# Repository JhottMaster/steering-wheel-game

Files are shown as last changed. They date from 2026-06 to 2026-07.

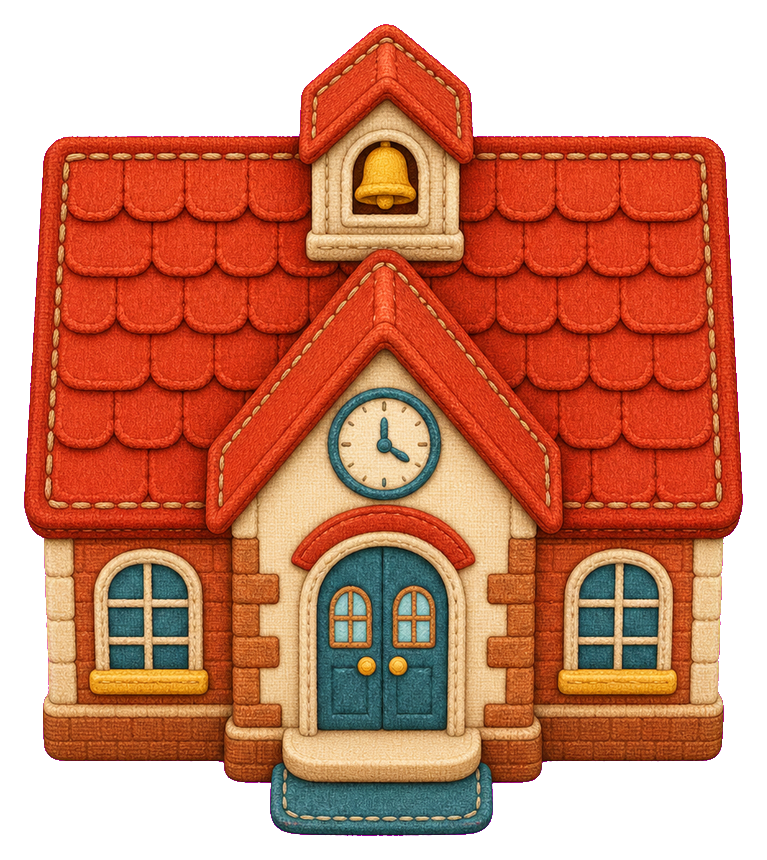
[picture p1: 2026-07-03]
controller_game/assets/sprites/building_school_ai_01.png

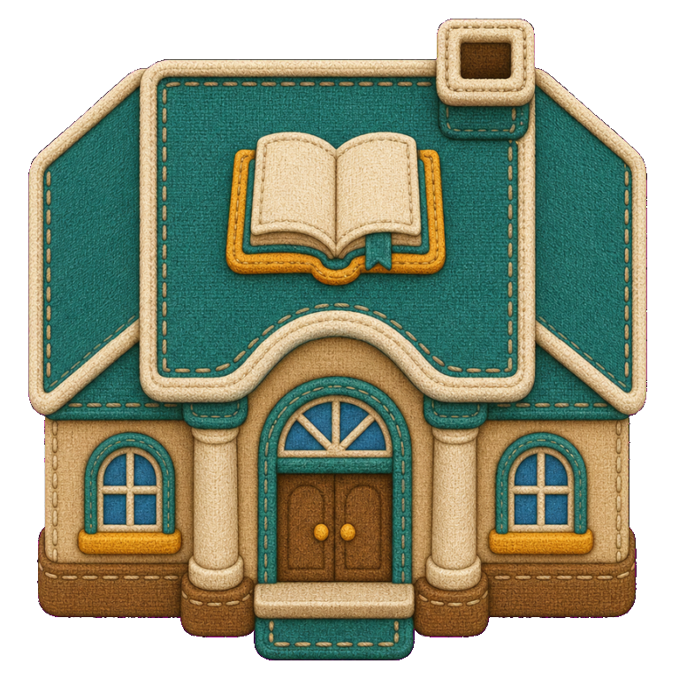
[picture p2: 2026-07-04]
controller_game/assets/sprites/building_library.png

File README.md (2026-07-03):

# Toddler Steering Wheel

This repo contains the CAD work, firmware, and game experiments for the toddler steering wheel project.

## Main Parts

- [`controller_game`](controller_game): the shared `raylib` game code for both Windows desktop development and Raspberry Pi console deployment
- [`firmware`](firmware): microcontroller sketches for streaming steering data
- [`docs`](docs): project notes and setup docs
- [`toddler_steering_wheel.py`](toddler_steering_wheel.py): CADQuery model for printed parts

## Shared Game Workflow

The game now lives in [`controller_game`](controller_game) and is configured for:

- Raspberry Pi OS `Lite`
- `raylib` built with `PLATFORM_DRM`
- fixed `1920x1080` output
- `UDP` controller input on port `4210`
- the existing Windows `MSYS2` desktop build loop

Quick path on the Pi:

```bash
sudo apt update
sudo apt install -y git build-essential \
  libdrm-dev libegl1-mesa-dev libgles2-mesa-dev libgbm-dev libasound2-dev

git clone --depth 1 https://github.com/raysan5/raylib.git
cd raylib/src
make PLATFORM=PLATFORM_DRM

cd /path/to/steering-wheel-game/controller_game
make -f Makefile.raspberry_pi
./build/bin/steering_wheel_console
```

For Windows desktop work, run:

```text
controller_game\windows_build.bat
controller_game\windows_test.bat
```

For Windows-to-Pi remote deploys, use:

```text
controller_game\deploy_to_raspberry_pi.bat
controller_game\stop_raspberry_pi_game.bat
```

Create `controller_game\raspberry_pi_config.bat` from `controller_game\raspberry_pi_config.example.bat` before deploying. The deploy script copies the game package to the Pi, builds it remotely, stops any running copy, starts the new build detached, and writes runtime logs to `/tmp/steering_wheel_console.log`.

More detail is in [`controller_game/README.md`](controller_game/README.md).

Game source layout and future-edit guidelines are in [`controller_game/DEVELOPMENT_GUIDELINES.md`](controller_game/DEVELOPMENT_GUIDELINES.md).

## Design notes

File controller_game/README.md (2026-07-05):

# Steering Wheel Controller Game

Shared `raylib` game code for both the Windows desktop dev loop and the Raspberry Pi console build.

`src/main.cpp` owns the app setup and frame loop so it remains a useful starting point. Most modules keep their implementation in the header to make browsing the game easier. The rest of `src/` is organized by responsibility:

- `src/game/`: Road Carpet Drive logic, assets, audio, and game rendering
- `src/app/`: shared app-level state such as app mode, logical controller buttons, and pause menu behavior
- `src/input/`: shared controller packet polling and packet-to-`SensorFrame` parsing behavior
- `src/views/`: secondary screens such as the hardware test dashboard
- `src/platform/`: Windows and Linux/Raspberry Pi networking, local IP lookup, and window defaults

This keeps networking, local IP discovery, window defaults, and small `raylib` API differences out of gameplay code.

Project structure preferences are captured in [`DEVELOPMENT_GUIDELINES.md`](DEVELOPMENT_GUIDELINES.md). In short: prefer header-oriented modules for this small game, keep `main.cpp` readable enough to understand the frame loop, and keep platform-specific socket/window details behind `src/platform/`.

## What It Does

- listens on `UDP` port `4210`
- expects packets like:

```text
qw=0.996,qx=0.012,qy=-0.084,qz=0.018,button1=0,button2=1
```

- the current controller firmware sends on input change and also forces a heartbeat packet at least every `200ms`
- on startup, the game immediately advertises itself over `UDP` broadcast on port `4211` so a controller can discover it
- once a controller is connected, the game stops broadcasting and only resumes if packets go stale for more than `5` seconds
- while rediscovering, the game sends a discovery beacon every `3` seconds and shows a disconnected banner in the game view

- defaults to the Road Carpet Drive game
- starts paused so a controller-only Raspberry Pi boot lands on a usable menu before gameplay begins
- press `T` to show the hardware test dashboard
- drives a toy car around a spreadsheet-authored toy-carpet city map
- uses generated sprites from `assets/sprites`
- draws roads, buildings, trees, bushes, coins, and spawn markers from `assets/cities/demo_city.csv`
- the current demo city has `32` collectible coins and `34` building props
- uses the CSV city data for spawn position, coin pickup, road/off-road behavior, and obstacle collision
- starts in button-throttle mode by default, with the car stopped until you accelerate
- gives button-throttle mode a higher top speed than auto-drive
- kicks up fading dust puffs and clamps speed harder when the car leaves the road
- adds animated kraken road encounters that wobble, growl when approached, and sink away when collected
- renders a steering wheel from quaternion-derived twist around the selected sensor axis
- displays the latest quaternion, derived Euler readout, and two button states from the controller
- shows `button2` as the red left lamp and `button1` as the green right lamp in test mode
- falls back to keyboard input if no recent packets arrive
- keeps the in-game HUD minimal: coins and speed stay visible, while diagnostics such as IP, FPS, and zoom live in the pause menu
- logs lightweight frame timing diagnostics to the terminal every `2` seconds while running
- desktop builds now default to a `1024x768` window to match the Raspberry Pi target layout more closely

## Controls

- `T`: toggle Road Carpet Drive / hardware test dashboard
- `A`: toggle auto-drive / button-throttle mode in the game
- in button-throttle mode, `button1` / up arrow accelerates
- in button-throttle mode, `button2` / down arrow brakes to a stop first and only engages reverse after the car has remained stopped for about `1` second
- `P`: use the sensor pitch-axis twist for steering
- `R`: use the sensor roll-axis twist for debug comparison
- `Y`: use the sensor yaw-axis twist for debug comparison
- `SPACE`: set the current sensor orientation as center
- controller recenter gesture: hold green (`button1`) and press red (`button2`) `3` times within `1.5` seconds
- controller pause gesture: hold green + red together for `3` seconds
- pause menu: steer left/right to choose, green selects, red resumes/goes back
- keyboard testing: up arrow also acts like green, down arrow also acts like red
- pause menu options: resume, restart, center wheel, quit, toggle acceleration mode, hardware test/back to game, zoom out, and zoom in
- left / right arrows: keyboard steering fallback input that automatically returns to center when released
- up arrow: desktop accelerate input in button-throttle mode
- down arrow: desktop brake/reverse input in button-throttle mode
- `-` / `=`: zoom the game camera out / in while tuning the city
- `0`: reset the game camera zoom
- `E`: toggle road art editor mode for tuning one hard-coded road piece and showing collision outlines
- in road art editor mode, `` ` `` / `~` toggles whether up/down selects the asset type or value field
- in road art editor field selection, up/down selects `scale_percent`, `footprint_percent`, `offset_x`, `offset_y`, `anchor_x`, or `anchor_y`
- in road art editor asset selection, up/down selects the road piece to tune
- in road art editor mode, left/right adjusts the selected value by `1` and auto-saves the config
- `F11`: toggle fullscreen on desktop builds
- `ESC`: quit

## Steering Notes

- gameplay steering uses quaternion-derived twist from the controller, not raw Euler steering angles
- the game tracks accumulated wheel rotation up to a `270` degree full-lock range instead of flipping direction after a half turn
- a small deadzone and blended response curve make it less twitchy near center while still giving stronger steering early in the turn
- reverse steering is automatically inverted so backing up behaves like a real car

## Assets

Generated game assets live in:

```text
assets/cities/
assets/sprites/
assets/sounds/
```

The current visual city is defined by:

```text
assets/cities/demo_city.csv
```

The carpet background is tiled from `terrain_carpet_tilemirror.png`; roads, props, buildings, coins, and the car are separate sprites drawn on top.

Fixed sprite filenames are used so the art can be replaced later without changing map files:

- `terrain_carpet_tilemirror.png`
- `road_horizontal_repeat.png`
- `road_vertical_repeat.png`
- `road_intersection_4way_crosswalks.png`
- `road_curve_bottom_right.png`
- `road_curve_bottom_left.png`
- `road_curve_top_right.png`
- `road_curve_top_left.png`
- `coin_star.png`
- `kraken_octopus_pop_sheet.png`
- `kraken_octopus_road_sheet.png`
- `toy_sports_car.png`
- `toy_car_tire.png`
- building sprites such as `building_house.png`, `building_shop.png`, and `building_fire_station.png`
- prop sprites such as `prop_bush_cluster.png`, `prop_evergreen.png`, and `prop_tree_round_ai_01.png`

Road curve filenames should match their semantic direction. For example, `road_curve_bottom_left.png`
is the art used by `CitySprite::kRoadCurveBottomLeft` and the `r_bl` city token.

Sound assets include:

- `carpet_cruise_loop.wav`
- `engine_large.ogg`, falling back to `toy_engine_loop.wav`
- `coin_chime.wav`
- `silent_beast_growl.mp3`: plays when an uncollected kraken first comes near the car
- `splash1.wav`: plays when a kraken is collected and sinks away
- optional fallback names `kraken_growl.wav` and `kraken_sink.wav` are also supported

To regenerate the current original art and sounds:

```text
python tools/generate_sounds.py
```

To regenerate simple procedural placeholder art that uses the same filenames loaded by the game:

```text
python tools/generate_assets.py
```

Some art helper scripts live in `tools/`, including tile mirroring and road alpha processing.

For quick city-layout tweaks without launching the game, there is also a lightweight visual CSV
editor:

```text
python tools/city_csv_editor.py
```

It shows the town as a clickable grid, includes row/column plus world-position data for each tile,
shows sprite previews behind the labels when available, and lets you edit/save the raw
pipe-separated cell contents directly.

## City CSV Format

The city map uses a spreadsheet-friendly CSV where each row is map `Y`, each column is map `X`, and each cell contains a pipe-separated list of things to draw in that tile.

Blank cells mean "just draw the tiled carpet background." A cell can contain one road tile plus any number of visual objects:

```csv
,,,,r_br,r_h|coin:star,r_h,r_bl
,house@256:280,,,r_v|coin:star
```

Cell contents use this shape:

```text
token
token@x:y
token@x:y*scale
token|token@x:y|token
```

Offsets are local tile pixels in a `512 x 512` authoring coordinate space, so `@256:256` means the center of a tile. The game currently renders each authored tile as `256 x 256` world pixels, which keeps the spreadsheet readable while making the city more compact. If an object has no offset, the parser places it at the tile center.

Current road tokens:

- `r_h`: horizontal road
- `r_v`: vertical road
- `r_x`: 4-way intersection
- `r_br`: curve connecting bottom and right
- `r_bl`: curve connecting bottom and left
- `r_tr`: curve connecting top and right
- `r_tl`: curve connecting top and left

Current object tokens:

- `coin:star`
- `kraken:pop`
- `kraken:road`
- `spawn:player`
- `tree:round`
- `tree:evergreen`
- `bush`
- `house`
- `shop`
- `school`
- `police`
- `fire_station`
- `library`

The parser for this format is in `src/game/city_map.h`. The same parsed city data drives rendering and gameplay:

- road tokens create drivable road shapes
- coin tokens create collectible coins
- kraken tokens create animated road encounters that pop/fade away when the car drives through them
- the HUD shows collected krakens separately from coins
- `spawn:player` sets the starting car position
- trees, bushes, and buildings create approximate obstacle collision shapes

Collision is intentionally based on authored geometry, not sprite alpha pixels. That keeps gameplay stable even as art is resized, feathered, or replaced.

Road art placement is tuned separately from road collision. Per-piece visual scale,
footprint scale, `X/Y` offsets, anchor edges, and draw mode live in
`assets/config/road_art_tuning.csv`, so straight roads, each curve direction, and intersections can
be nudged independently while the CSV tokens and collision shapes stay stable. `scale_percent`
shrinks or grows the art within its drawing box; `footprint_percent` shrinks or grows that drawing
box relative to the authored tile and can go above `100` when a sprite, such as the 4-way
intersection, needs to draw outside its logical collision tile. Anchor values are stepped positions:
`-1`, `0`, and `1` mean top/left, center, and bottom/right, while values beyond that intentionally
push the drawing box farther outside the logical tile. The in-game road art editor toggled by `E` can edit any configured road
sprite, auto-saves this config as values change, and overlays the current gameplay collision
geometry. Cyan outlines are drivable road shapes from the CSV tokens, orange outlines are obstacle
collision shapes, and the pale circle is the car collision radius.

## Build And Run

### Windows Desktop Loop

This keeps the same fast local workflow:

```text
windows_build.bat
windows_test.bat
```

The Windows build first checks for a `raylib` checkout at `..\raylib`. If that is missing, it falls back to the MSYS2 MINGW64 raylib package, or you can set `RAYLIB_DIR`.

The Windows executable is statically linked against `libraylib.a` when available, so double-clicking `build\bin\steering_wheel_game.exe` does not require `libraylib.dll` beside it.

### Raspberry Pi Console Build

Build `raylib` for `PLATFORM_DRM`, then from this folder run:

```bash
make -f Makefile.raspberry_pi
./build/bin/steering_wheel_console
```

By default the Pi build expects `raylib` at `~/raylib`. Override that with:

```bash
make -f Makefile.raspberry_pi RAYLIB_DIR=/path/to/raylib
```

This Pi build uses the same gameplay code, but switches to a fixed `1920x1080` console-style setup.

The Raspberry Pi makefile links `-latomic` because the Pi 3 toolchain may need it for raylib's audio code.

At startup, the Pi build now performs a small network preflight before entering the frame loop. If it
cannot find an active non-loopback IPv4 address or cannot open the UDP listener / broadcast socket, it
logs a `[startup] ...` message to stdout and exits early instead of taking over the screen with a game
session that cannot accept controller traffic.

Keyboard fallback is still useful for the Windows desktop loop, but it should currently be treated as
best-effort only on the Raspberry Pi `PLATFORM_DRM` build. The game code does poll raylib keyboard
state on Pi too, but in practice the console build may not receive normal key events reliably even
though kernel-level shortcuts such as `Ctrl` + `Alt` + `Del` still work.

## Remote Pi Deploy Loop

For Windows-to-Pi development, run these scripts from the real Windows shell in `controller_game/`:

```text
deploy_to_raspberry_pi.bat
run_raspberry_pi_game.bat
deploy_and_run_raspberry_pi.bat
stop_raspberry_pi_game.bat
```

In Codex, these scripts must run with approval/escalation so they use the real Windows `ssh`, `scp`, and `tar` tools. If they are run in the default sandbox, `ssh` may resolve to a deny shim instead of contacting the Pi.

The deploy script is the fast compile-feedback path. It:

- syncs the shared game files to the Pi over `ssh` / `scp`
- runs `Makefile.raspberry_pi` remotely and streams build errors back to your terminal

It intentionally does not stop or launch the game. That keeps most Pi iterations focused on whether the code compiles:

```text
deploy_to_raspberry_pi.bat
```

The run script:

- stops the previous game process if one is running
- launches the already-built Pi binary detached
- writes runtime output to `/tmp/steering_wheel_console.log`

Use it after a successful deploy/build when you want to update the Pi display:

```text
run_raspberry_pi_game.bat
```

Use the wrapper when you want the old one-command behavior:

```text
deploy_and_run_raspberry_pi.bat
```

The stop script only runs the remote process stop step, which is useful when the Pi game is already running and you want the display back.

For the persistent boot service on the Pi, the current stable setup is the plain `pablo` user service
plus a small drop-in override:

```ini
[Unit]
ConditionPathExists=!/boot/firmware/NO_GAME
ConditionPathExists=!/boot/NO_GAME

[Service]
SupplementaryGroups=input video render
ExecStartPre=/bin/sleep 5
```

That extra sleep gives Wi-Fi a moment to finish coming up during boot, and the `NO_GAME` sentinel file
provides an easy escape hatch if you ever need the Pi to boot to the console without launching the game.
Launching the service through `openvt` as root did attach it to `tty1`, but it was not worth the tradeoff,
so the recommended setup remains the non-root service above.

Create a local `raspberry_pi_config.bat` from `raspberry_pi_config.example.bat` and fill in your Pi host, username, remote path, and raylib path first:

```text
set "PI_HOST=raspberry-pi-game"
set "PI_USER=pablo"
set "PI_REMOTE_DIR=/home/pablo/steering-wheel-game/controller_game"
set "PI_RAYLIB_DIR=/home/pablo/raylib"
```

Absolute Linux paths are the safest choice for `PI_REMOTE_DIR` and `PI_RAYLIB_DIR`. SSH keys are recommended so deploys do not prompt for a password on every `ssh` / `scp` step.

On a 1 GB Raspberry Pi 3 B, compiling while the game is running may be tight on memory. If the remote build is terminated unexpectedly, stop the game first and rerun the build-only deploy:

```text
stop_raspberry_pi_game.bat
deploy_to_raspberry_pi.bat
```

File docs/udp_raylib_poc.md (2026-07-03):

# UDP Raylib POC

This proof of concept connects the current hardware bring-up to a very small cross-platform game shell:

- `XIAO ESP32-C3`
- `BNO055`
- `Wi-Fi UDP`
- `raylib` desktop app on Windows or Linux

## Goal

Show a simple top-down Road Carpet Drive game by default, with a `T`-toggle hardware test dashboard that visualizes BNO055 orientation and button input.

## Repo Layout

- [controller_poc/src/main.cpp](C:\Users\Pablo\Desktop\Projects\3D Printing\Toddler Steering Wheel\steering-wheel-game\controller_poc\src\main.cpp)
- [controller_poc/Makefile](C:\Users\Pablo\Desktop\Projects\3D Printing\Toddler Steering Wheel\steering-wheel-game\controller_poc\Makefile)
- [controller_poc/windows_build.bat](C:\Users\Pablo\Desktop\Projects\3D Printing\Toddler Steering Wheel\steering-wheel-game\controller_poc\windows_build.bat)
- [firmware/xiao_bno055_udp_sender/xiao_bno055_udp_sender.ino](C:\Users\Pablo\Desktop\Projects\3D Printing\Toddler Steering Wheel\steering-wheel-game\firmware\xiao_bno055_udp_sender\xiao_bno055_udp_sender.ino)

## Data Path

1. The XIAO reads fused orientation data from the BNO055.
2. The XIAO sends packets over Wi-Fi using `UDP`.
3. The `raylib` app listens on port `4210`.
4. In game mode, the app steers a toy car on a generated road-carpet map using quaternion-derived twist around the sensor pitch axis by default.
5. In hardware test mode, the app rotates an on-screen steering wheel based on the selected incoming quaternion-derived axis twist.

Packet format:

```text
qw=0.996,qx=0.012,qy=-0.084,qz=0.018,button1=0,button2=1
```

The current firmware sends immediately when orientation or button state changes, and also forces a small heartbeat packet at least every `200ms` so the app can detect stale/disconnected controllers more reliably.

## Firmware Setup

The tracked firmware sketch uses a local secrets header:

- tracked template: `firmware/xiao_bno055_udp_sender/wifi_secrets.example.h`
- local untracked file: `firmware/xiao_bno055_udp_sender/wifi_secrets.h`

Copy the example structure into the local header and fill in:

```text
REPLACE_WITH_WIFI_SSID
REPLACE_WITH_WIFI_PASSWORD
REPLACE_WITH_HOST_IP
```

`REPLACE_WITH_HOST_IP` is now mainly a fallback / reference value. In the current discovery flow, the controller waits for the game server to advertise itself over UDP broadcast before it marks setup complete.

Important note:

- attach the XIAO's external Wi-Fi / BLE antenna before expecting reliable wireless behavior
- the firmware sets a friendlier Wi-Fi hostname: `steering-wheel-poc-esp32c3`
- the serial monitor prints explicit `UDP #... sent to ...` lines for successful sends
- after Wi-Fi connects, the controller keeps the status LED in the breathing setup state until it hears a valid server discovery broadcast on UDP `4211`
- once discovery succeeds, the controller locks onto that sender IP for the rest of the run and stops listening for other servers
- once runtime starts, the controller sends on input change and also guarantees at least one UDP packet every `200ms`

## Serial Diagnostics

Open Serial Monitor at `115200` after upload. The firmware prints:

- the expected XIAO pin map for `BNO055`, buttons, and status LED
- initial button states, followed by button state changes only when they happen
- an `I2C` scan before initializing the BNO055; the BNO055 should usually appear at `0x28`
- BNO055 sensor details after successful detection
- visible Wi-Fi networks, connection status changes, local IP, and signal strength
- a compact `Health:` block every `5` seconds with Wi-Fi status, UDP send count, quaternion orientation, calibration, and button states

Set `kSerialDebugEnabled` near the top of the firmware sketch to `false` for live use. That disables Serial output and skips troubleshooting-only scans/reports while keeping the controller, Wi-Fi, UDP packets, buttons, and status LED behavior active.

## Desktop App Behavior

- default mode is the Road Carpet Drive game
- `T` toggles between the game and hardware test dashboard
- `F11` toggles fullscreen
- `A` toggles auto-drive / button-throttle mode in the game
- `P` uses quaternion-derived twist around the sensor pitch axis for steering
- `R` uses quaternion-derived twist around the sensor roll axis for debug comparison
- `Y` uses quaternion-derived twist around the sensor yaw axis for debug comparison
- `SPACE` captures the current sensor orientation as the center, so switching between the three twist axes stays calibrated
- `A` / `D` or left / right arrows provide a keyboard steering fallback when packets are not arriving
- `W` / up arrow and `S` / down arrow provide keyboard acceleration/brake fallback in button-throttle mode
- the app displays the latest quaternion values, derived Euler readout, `button1`, and `button2` values from UDP packets
- the hardware test dashboard shows `button2` as a red lamp on the left and `button1` as a green lamp on the right
- the app shows the host IPv4 address in the window so it is easy to confirm which machine is advertising itself on the LAN
- the app keeps the last received value on screen even if packets go stale
- on startup, the game immediately sends a small UDP broadcast beacon on port `4211` so a booting controller can discover it
- once controller packets are flowing, the game stops broadcasting and only resumes if packets have been stale for more than `5` seconds
- while rediscovering, the game sends the beacon every `3` seconds and shows a disconnected banner in the game view
- in manual drive mode, the green button accelerates, the red button brakes, and reverse only engages after the car has been fully stopped for about `1` second

## Game Assets

The game uses generated original assets in `controller_poc/assets`:

- `road_carpet_map_2.png`
- `sports_car_top.png`
- `coin.png`
- `carpet_cruise_loop.wav`
- `toy_engine_loop.wav`
- `coin_chime.wav`

`toy_car_top.png` is kept as an alternate car sprite.

Run `python tools/generate_assets.py` and `python tools/generate_sounds.py` from `controller_poc` to regenerate the current art and sound assets.

## Controller GPIO

The current XIAO ESP32-C3 firmware uses:

| Function | XIAO pin | Wiring |
| --- | --- | --- |
| `BNO055 SDA` | `D4` | sensor `SDA` |
| `BNO055 SCL` | `D5` | sensor `SCL` |
| `button1` | `D1` | button to `GND`, uses `INPUT_PULLUP` |
| `button2` | `D2` | button to `GND`, uses `INPUT_PULLUP` |
| status LED | `D10` | GPIO -> resistor -> LED -> `GND` |

Status LED wiring notes:

- A `330 ohm` resistor is a good default for a normal green LED on `3.3V`.
- The `560 ohm` resistor with `green-blue-brown-gold` bands is also safe; it will just be dimmer.
- The resistor can go on either side of the LED and has no direction.
- The LED does have direction: long leg / round side is the anode and goes toward `D10`; short leg / flat side is the cathode and goes to `GND`.

Status LED states:

- slow breathing: setup is still in progress, starting as soon as the sketch boots
- brief off beat, then rapid flash for about `0.5` seconds: setup completed and Wi-Fi connected
- solid: runtime is healthy and data transmission has started
- `500ms` on/off blink: error state

The status LED is driven by a millis-based state machine. Wi-Fi setup, retry waits, and debug Wi-Fi scanning all call the LED updater instead of playing blocking LED animations with long `delay(...)` calls.

## Build Notes

### Windows

The POC expects a `raylib` checkout at `controller_poc/../raylib` by default, similar to your existing workflow. If needed, set `RAYLIB_DIR` before building.

Run logic tests with `windows_test.bat`.

### Linux

The POC expects a system `raylib` package discoverable through `pkg-config`.

## Suggested First Test

1. Build and launch the `raylib` app.
2. Confirm Road Carpet Drive loads by default.
3. Fill in Wi-Fi credentials in `wifi_secrets.h`.
4. Upload the firmware.
5. Launch the game first so it begins broadcasting discovery beacons immediately.
6. Confirm the controller fast-flashes once it locks the server IP, then switches to live `UDP` steering input.
7. Press `T` to verify the hardware test dashboard.

## Real-World Networking Notes

This was verified working on a network where the Windows PC and XIAO were on different VLANs / network segments.

What mattered in practice:

- Windows needed an inbound firewall allow rule for the app or UDP port `4210`
- the router also needed an allow rule for UDP traffic between the relevant network segments
- local loopback testing from PowerShell to the app was useful to separate app issues from network issues

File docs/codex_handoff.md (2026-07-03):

# Toddler Steering Wheel Game - Codex Handoff

## Project Goal

Build a small handheld steering wheel toy for a toddler. The physical wheel should be 3D printable and eventually contain an ESP32-class microcontroller, an IMU/gyro sensor, and a battery/power source. The longer-term idea is to use the wheel as a game controller, likely sending steering/tilt data to a browser game or desktop app over BLE or Wi-Fi.

CadQuery is the source of truth for the CAD model. The model should stay parametric, with important dimensions declared as variables near the top of the Python file.

## Repo And Location

Local project folder:

```text
C:\Users\Pablo\Desktop\Projects\3D Printing\Toddler Steering Wheel\steering-wheel-game
```

GitHub repo:

```text
git@github.com:JhottMaster/steering-wheel-game.git
```

Main CAD file:

```text
toddler_steering_wheel.py
```

Generated exports:

```text
toddler_steering_wheel.step
toddler_steering_wheel.stl
```

## Environment

The repo now has a working Windows local Python virtual environment:

```text
.venv
```

On Windows 11, confirmed working packages include:

```text
cadquery==2.5.2
cq-editor==0.5.0
```

There is also historical macOS setup context from the earlier machine where `uv` was used because `conda`/`mamba` were not visible from the Codex shell.

Cross-platform environment/setup notes now live here:

```text
docs/environment_setup.md
```

## Useful Commands

Windows 11 regenerate STEP and STL:

```powershell
.\.venv\Scripts\python toddler_steering_wheel.py
```

Windows 11 open in CQ-editor:

```powershell
.\launch_cq_editor_windows.bat
```

macOS regenerate STEP and STL:

```bash
.venv/bin/python toddler_steering_wheel.py
```

macOS open in CQ-editor:

```bash
QT_ENABLE_HIGHDPI_SCALING=0 .venv/bin/cq-editor toddler_steering_wheel.py
```

## CQ-editor Display Bug

CQ-editor had a macOS HiDPI/Retina scaling issue where the 3D viewport rendered only into a small part of the preview area. Launching with this environment variable fixed it:

```bash
QT_ENABLE_HIGHDPI_SCALING=0
```

On Windows 11, CQ-editor installed successfully in the repo-local `.venv`, but needed a wrapper launcher so Spyder config and `ezdxf` cache would use repo-local folders rather than user-home locations:

```text
launch_cq_editor_windows.bat
```

## Current CAD State

The current model is a simple steering wheel body meant as a first print to test size and hand feel.

Current important dimensions:

```text
wheel_outer_diameter = 180.0 mm
wheel_inner_diameter = 118.0 mm
wheel_thickness = 16.0 mm
hub_diameter = 54.0 mm
hub_thickness = 22.0 mm
spoke_count = 3
spoke_width = 20.0 mm
spoke_thickness = 14.0 mm
```

The wheel has rounded grip edges:

```text
grip_roundover_radius = 7.0 mm
hub_roundover_radius = 2.0 mm
spoke_roundover_radius = 2.0 mm
```

The original electronics pocket was likely to need support material when printing flat, so it is currently off:

```text
include_electronics_pocket = False
include_center_hole = False
include_mounting_holes = False
```

Instead, there is a shallow front inset to show the approximate electronics footprint without requiring supports:

```text
include_pocket_footprint_inset = True
pocket_width = 34.0 mm
pocket_height = 48.0 mm
pocket_footprint_inset_depth = 1.2 mm
```

The pocket size was a rough guess for a small ESP32/Arduino Nano-style board plus an IMU breakout. It is not yet based on a chosen board, but the first print confirmed that a real electronics cavity can likely fit a `XIAO ESP32-C3` and `BNO055` side by side if the current shallow hub area is made deeper.

## Printing Notes

Printer:

```text
Bambu Lab P1P
```

Build volume is large enough for this model. The wheel is currently about 180 mm across, fitting comfortably on the 256 mm bed.

Recommended first prototype:

```text
Print flat, face-up.
Use the current no-real-pocket STL.
Purpose: test toddler hand feel, grip size, and overall diameter.
```

The current shallow inset should not create the same support problem as the deeper rear electronics pocket.

## Electronics Discussion So Far

Likely components:

```text
Seeed Studio XIAO ESP32-C3
Adafruit BNO055 absolute orientation sensor
battery/power source still undecided
cover plate screwed into the hub
heat-set brass inserts for screws
```

Other parts found in the parts bin during hardware inventory:

```text
generic ESP32 board
Adafruit ItsyBitsy 48 MHz 3.3V
Adafruit Bluetooth Feather
Arduino Micro
Meadow board
Adafruit LIS3DH 3-axis accelerometer
LC Studio MMA7361-style 3-axis accelerometer board
```

Reasoning behind the current preferred stack:

```text
XIAO ESP32-C3 is very small and has USB-C for simple first-prototype power and programming.
BNO055 includes fused orientation and is the strongest sensor found so far for steering input.
LIS3DH and MMA7361 are usable fallbacks for rough tilt input but are accelerometer-only.
Arduino Micro remains a possible wired USB HID option later if pretending to be a keyboard/gamepad becomes the simplest Raspberry Pi integration path.
```

For the final electronics version, consider:

```text
two-piece hub with screw-on rear cover
heat-set insert pockets/standoffs
proper battery retention
secure cover screws
no exposed coin cells or loose small parts for toddler use
```

## Validated Bring-Up Status

As of `2026-05-31`, the following combination has been tested successfully over `USB-C`:

```text
Seeed Studio XIAO ESP32-C3
Adafruit BNO055
I2C connection
USB serial output from a simple Arduino sketch
```

This de-risks the most important early electronics question: the current preferred controller and sensor stack works well enough to proceed with a real prototype.

The successful smoke-test sketch and setup notes are now in the repo:

```text
docs/xiao_bno055_bringup.md
firmware/xiao_bno055_smoketest/xiao_bno055_smoketest.ino
```

There is also now a shared Windows/Raspberry Pi raylib game in the repo:

```text
controller_game/
docs/udp_raylib_poc.md
firmware/xiao_bno055_udp_sender/xiao_bno055_udp_sender.ino
```

Current game development preferences are captured here:

```text
controller_game/DEVELOPMENT_GUIDELINES.md
```

Current test wiring:

```text
XIAO 3V3 -> BNO055 VIN
XIAO GND -> BNO055 GND
XIAO D4/SDA -> BNO055 SDA
XIAO D5/SCL -> BNO055 SCL
```

Current first-prototype power strategy:

```text
Use USB-C to power and program the XIAO.
Do not block on battery selection before the first real electronics prototype.
Expose the XIAO USB-C port in the CAD revision.
```

Additional bring-up notes:

```text
The XIAO ESP32-C3 does not expose a normal programmable onboard user LED.
The tiny red onboard light appears to be a power LED, not a general status LED to build around.
The smoke-test sketch includes a short quiet startup delay after reset to make reprogramming smoother.
```

## Validated Wi-Fi POC Status

As of `2026-05-31`, the Wi-Fi POC is also working end-to-end:

```text
XIAO ESP32-C3 reads orientation from BNO055
XIAO sends UDP packets over Wi-Fi
Raylib desktop app receives packets and displays a steering bar
Windows 11 test machine verified
```

Important practical notes from the working setup:

```text
The external XIAO antenna must be attached or Wi-Fi signal can be unusably weak.
The firmware uses a local untracked wifi_secrets.h file plus a tracked wifi_secrets.example.h template.
The XIAO now advertises a friendlier hostname: steering-wheel-poc-esp32c3
The Raylib app can display the host IPv4 address to make discovery/debugging easier.
The Windows app can receive local UDP test packets from PowerShell.
To get real XIAO-to-PC traffic working, both Windows firewall and router/VLAN UDP rules mattered.
```

## Likely Next Steps

1. Keep the current `XIAO + BNO055` wiring intact while it is known-good.
2. Refine the signal the game uses:
   - derive a more intentional steering value from roll/pitch
   - add better centering / calibration behavior
   - decide whether heading should be ignored for gameplay
3. Decide whether the first real game path stays on Wi-Fi UDP or also needs a wired USB fallback.
4. Revise the CAD around the real prototype electronics:
   - deeper hub cavity
   - XIAO and BNO055 placement
   - USB-C access slot
   - likely rear cover strategy
5. After the wired or Wi-Fi prototype works, revisit battery, charger, switch, and mounting hardware choices.

## Style Preference For Future CAD

Generate CadQuery Python scripts with:

```text
clear variables at top
CadQuery Workplane API
show_object(result)
STEP and STL exports
comments for key geometry blocks
simple geometry first, complexity only when needed
```

Prefer CadQuery over OpenSCAD. Keep CadQuery as the source of truth.

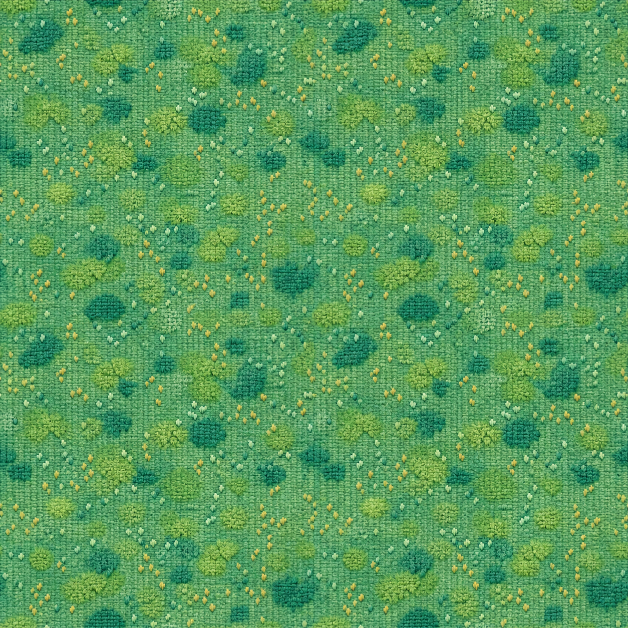
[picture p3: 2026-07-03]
controller_game/assets/sprites/terrain_carpet.png

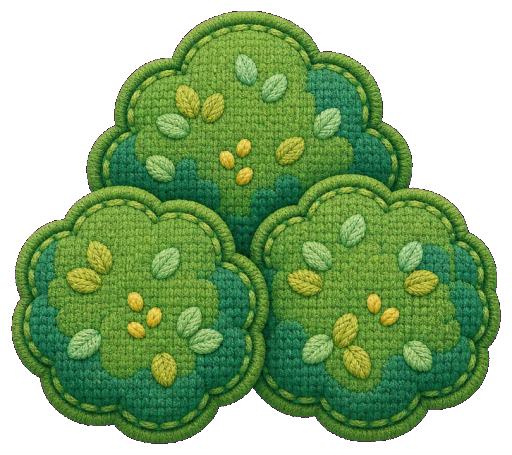
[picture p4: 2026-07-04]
controller_game/assets/sprites/prop_bush_cluster.png

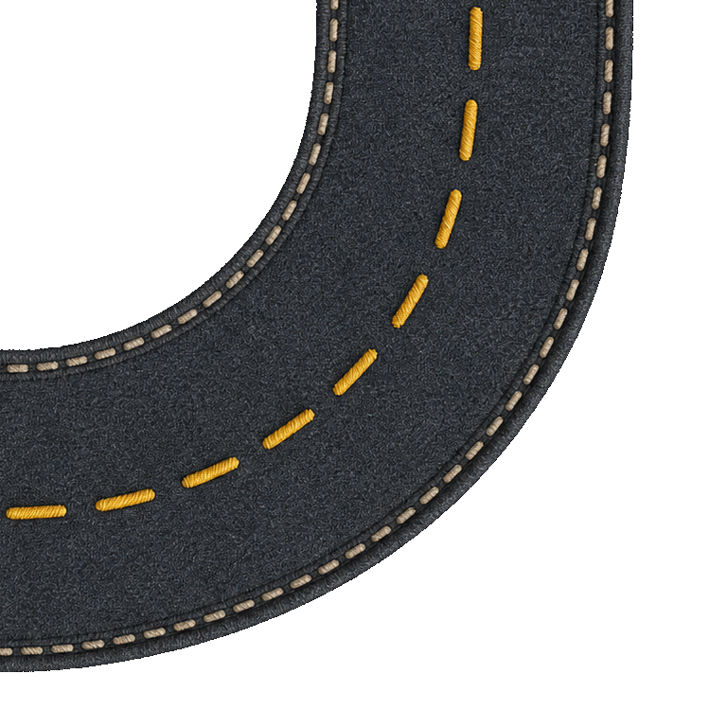
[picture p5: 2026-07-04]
controller_game/assets/sprites/road_curve_top_left.png

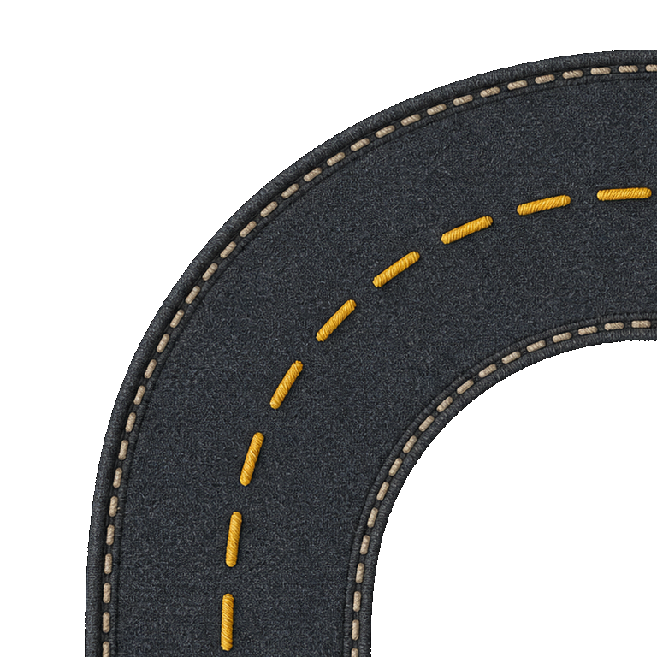
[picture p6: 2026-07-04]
controller_game/assets/sprites/road_curve_bottom_right.png

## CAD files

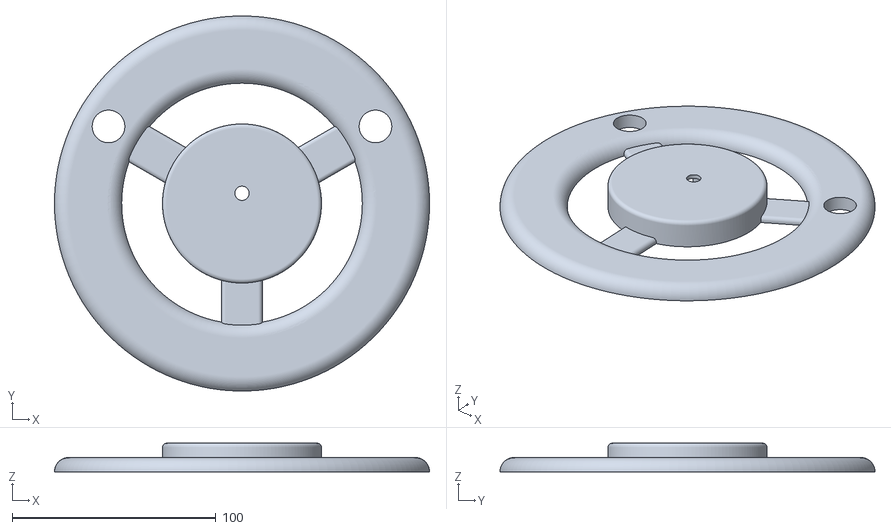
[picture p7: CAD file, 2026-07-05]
steering_wheel_front.stl
184.0 x 183.9 x 14.0

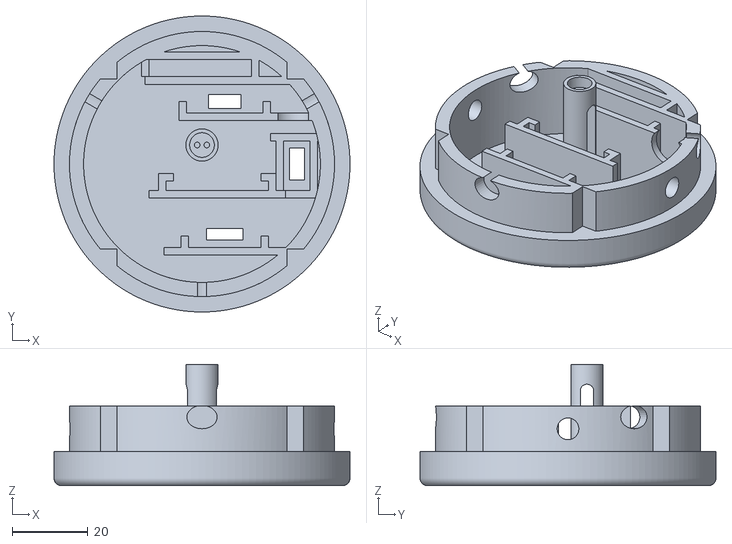
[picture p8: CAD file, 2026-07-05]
center_hub.stl
78.0 x 78.0 x 32.0

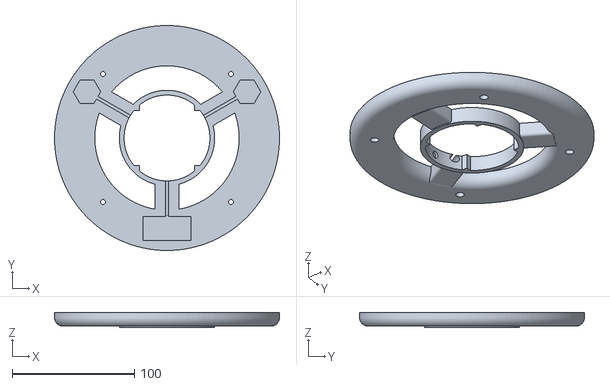
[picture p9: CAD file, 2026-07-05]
steering_wheel_back.stl
184.0 x 183.9 x 12.0

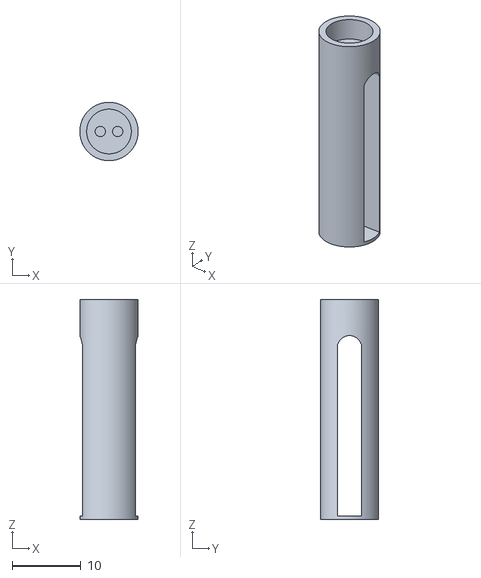
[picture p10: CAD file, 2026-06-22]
led_socket.stl
8.50 x 8.50 x 32.0

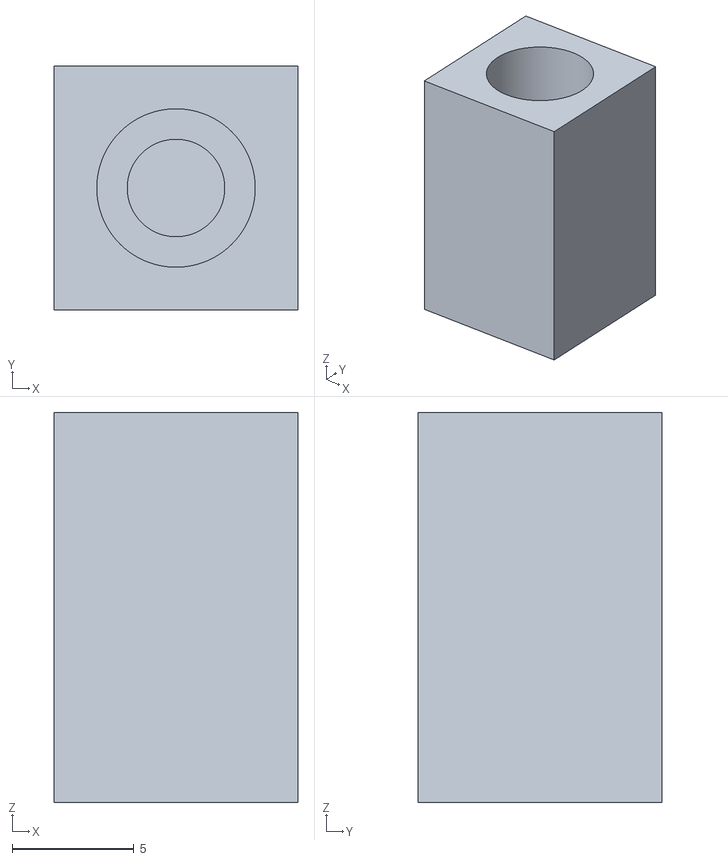
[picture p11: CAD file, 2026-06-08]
test_screw_block.stl
10.0 x 10.0 x 16.0

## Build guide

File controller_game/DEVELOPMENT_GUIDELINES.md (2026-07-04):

# Controller Game Development Guidelines

These notes capture the project shape we want to preserve while iterating quickly on the Windows desktop build and Raspberry Pi console build.

## Source Layout

- Keep `src/main.cpp` as the readable app entry point. It should own setup, the frame loop, mode switching, high-level input flow, update calls, and draw calls.
- Do not shrink `main.cpp` into a tiny launcher that only jumps to another file. Opening it should explain what the game does each frame.
- Keep gameplay, rendering helpers, input behavior, and platform code organized under the existing `src/` folders.
- Avoid scattering new tiny files unless the split makes navigation materially easier.

## Header-Oriented Modules

- Prefer modules where the header contains the implementation, especially for small game systems.
- Use a separate `.cpp` only when the distinction between interface and implementation adds real clarity or reduces meaningful compile/link pain.
- Mark header-defined functions `inline`.
- Put private helpers in a small `*_detail` namespace instead of an anonymous namespace, because multiple headers are included into the same translation unit.

## Platform Boundaries

- Keep platform-specific code in `src/platform/`.
- Platform files should handle OS details such as sockets, nonblocking datagram reads, local IP lookup, window defaults, and small raylib API differences.
- Shared behavior should stay outside platform files. For example, platform receivers expose one datagram at a time, while `src/input/sensor_receiver.h` owns the shared "drain packets and keep the latest valid `SensorFrame`" behavior.
- Avoid peppering gameplay files with `#ifdef`s. Prefer selecting the platform header once near the boundary.

## Build And Deploy

- Keep the Windows loop fast: `windows_build.bat` and `windows_test.bat` should remain the first verification path.
- Keep Raspberry Pi deployment isolated to the Pi scripts and `Makefile.raspberry_pi`.
- `deploy_to_raspberry_pi.bat` is the build-feedback path: sync and compile only.
- `run_raspberry_pi_game.bat` launches the already-built remote binary.
- `deploy_and_run_raspberry_pi.bat` is only the convenience wrapper when the display should update immediately.
- `stop_raspberry_pi_game.bat` should remain safe to run independently before memory-heavy Pi builds.
- When adding source folders that the Pi needs, update the deploy package list.
- The Pi build targets `1920x1080` and raylib `PLATFORM_DRM`.
- In Codex, SSH-based scripts need approval/escalation so they run with the real Windows OpenSSH tools instead of the sandbox deny shim.

## City Map Format

- Keep the authorable city map in `assets/cities/demo_city.csv`.
- Treat the CSV as a visual grid: row is map `Y`, column is map `X`, and each cell is a pipe-separated stack of tokens.
- Empty cells mean plain tiled carpet background; do not require a `grass` token.
- Prefer compact readable map tokens such as `r_h`, `r_v`, `r_x`, `coin:star`, and `tree:round@x:y`.
- Use the parsed city data for gameplay semantics; avoid runtime collision behavior based on rendered sprite alpha pixels.
- Roads should own simple drivable geometry, and props/buildings should own approximate collision shapes tuned for feel.
- Keep road visual tuning first-class and separate from gameplay geometry. Per-piece road art scale, footprint scale, offsets, anchor edges, and draw modes belong in `assets/config/road_art_tuning.csv`, with parsing/editor behavior in `src/game/road_art_tuning.h`.
- Keep road curve asset filenames aligned with their semantic enum/token direction; `road_curve_bottom_left.png` should be the asset loaded for `CitySprite::kRoadCurveBottomLeft` / `r_bl`.

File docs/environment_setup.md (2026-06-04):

# Environment Setup

This repo is used across multiple machines and operating systems. These are the working commands and notes for the current setup.

## Windows 11

### CadQuery CLI

Create and use the local virtual environment:

```powershell
python -m venv .venv
.\.venv\Scripts\python -m pip install cadquery
```

Run the CAD script:

```powershell
.\.venv\Scripts\python toddler_steering_wheel.py
```

This exports:

- `toddler_steering_wheel.step`
- `toddler_steering_wheel.stl`
- `toddler_steering_wheel_cartridge.step`
- `toddler_steering_wheel_cartridge.stl`

Important note:

- On this Windows setup, CadQuery/OCP was crashing during native shutdown after successful exports. The script now uses a CLI-only hard exit after export so command-line runs finish cleanly while CQ-editor behavior remains intact.

### CQ-editor on Windows

Install into the same virtual environment:

```powershell
.\.venv\Scripts\python -m pip install cq-editor
.\.venv\Scripts\python -m pip install "setuptools<81"
```

Launch with the project-local wrapper:

```powershell
.\launch_cq_editor_windows.bat
```

Why the wrapper exists:

- CQ-editor / Spyder wanted to write config under `C:\Users\Pablo\.spyder-py3`
- `ezdxf` wanted to write cache under `C:\Users\Pablo\.cache`
- `qtawesome` wanted to copy icon fonts under the Windows user font folder
- this repo now uses local folders instead:
  - `.local-config\spyder`
  - `.local-appdata`
  - `.local-cache`

The `setuptools<81` pin is required because CQ-editor imports `pkg_resources`, which is no longer available in newer `setuptools` releases.

## macOS

The earlier working environment used `uv` plus CQ-editor.

Typical setup:

```bash
uv venv
source .venv/bin/activate
uv pip install cadquery==2.7.0 cq-editor==0.7.0
```

Run exports:

```bash
.venv/bin/python toddler_steering_wheel.py
```

Open in CQ-editor:

```bash
QT_ENABLE_HIGHDPI_SCALING=0 .venv/bin/cq-editor toddler_steering_wheel.py
```

The HiDPI environment variable was important on macOS because CQ-editor rendered incorrectly without it on the previous machine.

## Repo Notes

- `firmware/xiao_bno055_udp_sender/wifi_secrets.h` is intentionally local-only and ignored by git.
- `.venv/`, `.local-config/`, `.local-appdata/`, and `.local-cache/` are also local-only and ignored.
- The current CAD model now exports both the wheel and a separate removable cartridge part.

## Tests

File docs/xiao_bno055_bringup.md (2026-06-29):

# XIAO ESP32-C3 + BNO055 Bring-Up

This is the fastest path to validate the riskiest part of the project:

- `Seeed Studio XIAO ESP32-C3`
- `Adafruit BNO055`
- `USB-C` power/data to a computer or Raspberry Pi

## Goal

Confirm all of the following as quickly as possible:

1. The XIAO can be programmed over `USB-C`.
2. The BNO055 is detected reliably over `I2C`.
3. We can print orientation data to `Serial` over USB.

## Wiring

Use `I2C` for the first test.

| XIAO ESP32-C3 | BNO055 |
| --- | --- |
| `3V3` | `VIN` |
| `GND` | `GND` |
| `D4 / SDA` | `SDA` |
| `D5 / SCL` | `SCL` |

Notes:

- On the XIAO ESP32-C3, Seeed maps `D4` to `SDA` and `D5` to `SCL`.
- The Adafruit BNO055 breakout accepts `3.3V` on `VIN`, so powering it from the XIAO `3V3` pin is fine.
- Keep the wires short for the first test. The BNO055 can be fussy on `I2C`.

Extra controller I/O for the current UDP POC:

| Function | XIAO ESP32-C3 | Wiring |
| --- | --- | --- |
| `button1` | `D1` | button to `GND`, firmware uses `INPUT_PULLUP` |
| `button2` | `D2` | button to `GND`, firmware uses `INPUT_PULLUP` |
| status LED | `D10` | `D10` -> resistor -> LED -> `GND` |

Status LED wiring notes:

- A `330 ohm` resistor is a good default for a normal green LED on `3.3V`.
- The `560 ohm` resistor with `green-blue-brown-gold` bands is also safe; it will just be dimmer.
- The resistor can go on either side of the LED and has no direction.
- The LED does have direction: long leg / round side is the anode and goes toward `D10`; short leg / flat side is the cathode and goes to `GND`.

Status LED behavior:

- slow breathing: setup is still in progress, starting as soon as the sketch boots
- brief off beat, then rapid flash for about `0.5` seconds: setup completed and Wi-Fi connected
- solid: runtime is healthy and the controller has started transmitting data
- `500ms` on/off blink: error state, such as BNO055 not detected or UDP/Wi-Fi send trouble

The status LED is driven by a millis-based state machine rather than blocking LED animation delays.

Set `kSerialDebugEnabled` near the top of the UDP firmware sketch to `false` for live use. This disables Serial output and skips troubleshooting-only scans/reports.

## Arduino IDE Setup

Use the current `Arduino IDE 2.x`.

1. Install Arduino IDE.
2. Open `File -> Preferences`.
3. Add this to `Additional Boards Manager URLs`:

```text
https://raw.githubusercontent.com/espressif/arduino-esp32/gh-pages/package_esp32_index.json
```

4. Open `Tools -> Board -> Boards Manager`.
5. Search for `esp32`.
6. Install the `esp32` package from `Espressif Systems`.
7. Select `Tools -> Board -> ESP32 Arduino -> XIAO_ESP32C3`.
8. Select the correct `Tools -> Port`.

Then install libraries with `Library Manager`:

- `Adafruit BNO055`
- `Adafruit Unified Sensor`

## Smoke Test Sketch

The sketch lives here:

- [xiao_bno055_smoketest.ino](C:\Users\Pablo\Desktop\Projects\3D Printing\Toddler Steering Wheel\steering-wheel-game\firmware\xiao_bno055_smoketest\xiao_bno055_smoketest.ino)

What it does:

- starts USB serial
- waits briefly after reset so repeated reprogramming is less annoying
- starts `I2C` on `D4` and `D5`
- slows the bus to `100 kHz`
- attempts to initialize the BNO055
- prints Euler orientation and calibration values repeatedly

## Test Procedure

1. Wire the boards.
2. Plug the XIAO into your computer with a data-capable `USB-C` cable.
3. Upload the smoke test sketch.
4. Open `Serial Monitor`.
5. Set baud to `115200`.
6. Press reset once if needed.

Success looks like:

- `BNO055 detected`
- repeated lines of heading / roll / pitch values
- calibration values changing as you move the sensor

## Known Risk

Adafruit notes that the BNO055 can have `I2C` compatibility issues with `ESP32`-family boards. The first purpose of this test is to find out whether `XIAO ESP32-C3 + BNO055` behaves well enough for us.

If it is unstable:

- keep wires shorter
- try a different USB cable
- power-cycle both boards
- try adding stronger `I2C` pullups later
- fall back to the `LIS3DH` or a different IMU if necessary

## QoL Notes

- The XIAO ESP32-C3 does not have a normal programmable onboard user LED. The tiny red LED visible on the board is effectively just a power indicator.
- The smoke-test sketch now includes a short quiet startup window after reset so the serial port is easier to reconnect to while iterating.

## Controller Direction

For the next prototype step, the fastest path into a `raylib` C++ game is:

1. keep using `USB-C`
2. send a compact steering value over `USB serial`
3. read that serial stream from the desktop or Raspberry Pi app

This is simpler than trying to start with `BLE HID` or a full USB gamepad emulation path.

## If This Passes

If the smoke test works, the next step is:

1. define the USB access slot in CAD
2. deepen the hub cavity
3. mount the XIAO and BNO055 as the first real electronics prototype

## Sources

- Seeed XIAO ESP32-C3 getting started: https://wiki.seeedstudio.com/XIAO_ESP32C3_Getting_Started/
- Adafruit BNO055 guide: https://learn.adafruit.com/adafruit-bno055-absolute-orientation-sensor

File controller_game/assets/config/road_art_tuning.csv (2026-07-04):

sprite | scale_percent | footprint_percent | offset_x | offset_y | anchor_x | anchor_y | draw_mode
road_horizontal | 29 | 100 | 0 | -7 | 0 | 0 | repeat_horizontal
road_vertical | 36 | 100 | 0 | 0 | 0 | 0 | repeat_vertical
road_intersection | 100 | 140 | 0 | 0 | 0 | 0 | stretch
road_curve_bottom_right | 80 | 99 | 6 | 60 | 1 | -1 | stretch
road_curve_bottom_left | 75 | 100 | 0 | 0 | -1 | 1 | stretch
road_curve_top_right | 90 | 89 | 7 | 0 | 1 | -2 | stretch
road_curve_top_left | 89 | 90 | -6 | -25 | -1 | -1 | stretch

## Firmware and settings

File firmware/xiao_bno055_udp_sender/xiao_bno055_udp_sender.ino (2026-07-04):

#include <WiFi.h>
#include <WiFiUdp.h>
#include <Wire.h>
#include <Adafruit_BNO055.h>
#include <Adafruit_Sensor.h>
#include <utility/imumaths.h>
#include "wifi_secrets.h"

namespace {
constexpr char kWifiHostname[] = "steering-wheel-poc-esp32c3";
constexpr uint16_t kHostPort = 4210;
constexpr uint16_t kDiscoveryPort = 4211;
constexpr char kDiscoveryMessage[] = "steering-wheel-server port=4210";
constexpr int kSdaPin = D4;
constexpr int kSclPin = D5;
constexpr int kButton1Pin = D1;
constexpr int kButton2Pin = D2;
constexpr int kStatusLedPin = D10;
constexpr int kSdaGpioNumber = 6;
constexpr int kSclGpioNumber = 7;
constexpr int kButton1GpioNumber = 3;
constexpr int kButton2GpioNumber = 4;
constexpr int kStatusLedGpioNumber = 10;
constexpr bool kSerialDebugEnabled = true;
constexpr uint32_t kBaudRate = 115200;
constexpr uint32_t kStartupQuietMs = 4000;
constexpr uint32_t kI2cClockHz = 100000;
constexpr uint32_t kPacketIntervalMs = 33;
constexpr uint32_t kHeartbeatIntervalMs = 200;
constexpr uint32_t kWifiConnectTimeoutMs = 12000;
constexpr uint32_t kWifiScanTimeoutMs = 8000;
constexpr uint32_t kWifiRetryDelayMs = 3000;
constexpr uint32_t kStatusLedBreathPeriodMs = 2200;
constexpr uint32_t kStatusLedBreathStepMs = 25;
constexpr uint32_t kStatusLedErrorFlashMs = 500;
constexpr uint32_t kStatusLedSetupCompleteFlashMs = 500;
constexpr uint32_t kStatusLedSetupCompleteToggleMs = 50;
constexpr uint32_t kStatusLedSetupCompleteBlankMs = 100;
constexpr uint32_t kHealthReportIntervalMs = 5000;
constexpr uint32_t kDiscoveryHeartbeatIntervalMs = 3000;
constexpr float kMinQuaternionDelta = 0.015f;
uint32_t wifiAttemptCount = 0;
uint32_t udpSendCount = 0;

Adafruit_BNO055 bno = Adafruit_BNO055(55, 0x28, &Wire);
WiFiUDP udp;
WiFiUDP discoveryUdp;
uint32_t lastPacketMs = 0;
bool hasLastSentFrame = false;
float lastSentQuatW = 1.0f;
float lastSentQuatX = 0.0f;
float lastSentQuatY = 0.0f;
float lastSentQuatZ = 0.0f;
bool lastSentButton1Pressed = false;
bool lastSentButton2Pressed = false;
bool hasLastReportedButtons = false;
bool lastReportedButton1Pressed = false;
bool lastReportedButton2Pressed = false;
uint32_t lastHealthReportMs = 0;
uint32_t lastSuccessfulSendMs = 0;
IPAddress hostIp;
bool hasHostIp = false;

enum class StatusLedMode {
  kSetupBreathing,
  kSetupCompleteFlash,
  kRuntimeSolid,
  kErrorBlink,
};

StatusLedMode statusLedMode = StatusLedMode::kSetupBreathing;
uint32_t statusLedModeStartMs = 0;
bool runtimeSolidPending = false;

class DebugSerialProxy {
 public:
  void begin(uint32_t baudRate) const {
    if (kSerialDebugEnabled) {
      ::Serial.begin(baudRate);
    }
  }

  explicit operator bool() const {
    return !kSerialDebugEnabled || static_cast<bool>(::Serial);
  }

  template <typename... Args>
  void print(Args... args) const {
    if (kSerialDebugEnabled) {
      ::Serial.print(args...);
    }
  }

  template <typename... Args>
  void println(Args... args) const {
    if (kSerialDebugEnabled) {
      ::Serial.println(args...);
    }
  }
};

DebugSerialProxy DebugSerial;
#define Serial DebugSerial

const char* wifiStatusToString(wl_status_t status) {
  switch (status) {
    case WL_IDLE_STATUS:
      return "idle";
    case WL_NO_SSID_AVAIL:
      return "ssid not available";
    case WL_SCAN_COMPLETED:
      return "scan completed";
    case WL_CONNECTED:
      return "connected";
    case WL_CONNECT_FAILED:
      return "connect failed";
    case WL_CONNECTION_LOST:
      return "connection lost";
    case WL_DISCONNECTED:
      return "disconnected";
    default:
      return "unknown";
  }
}

bool quaternionComponentChangedEnough(float previousValue, float currentValue) {
  return fabsf(currentValue - previousValue) >= kMinQuaternionDelta;
}

bool readButtonPressed(int pin) {
  return digitalRead(pin) == LOW;
}

void setStatusLed(bool enabled) {
  analogWrite(kStatusLedPin, enabled ? 255 : 0);
}

void setStatusLedBrightness(uint8_t brightness) {
  analogWrite(kStatusLedPin, brightness);
}

uint8_t breathingBrightness(uint32_t now) {
  const uint32_t halfPeriodMs = kStatusLedBreathPeriodMs / 2;
  const uint32_t phaseMs = now % kStatusLedBreathPeriodMs;
  const uint32_t rampMs = phaseMs < halfPeriodMs ? phaseMs : kStatusLedBreathPeriodMs - phaseMs;
  return static_cast<uint8_t>(map(rampMs, 0, halfPeriodMs, 8, 255));
}

void updateSetupStatusLed(uint32_t now) {
  setStatusLedBrightness(breathingBrightness(now));
}

void setStatusLedMode(StatusLedMode mode, uint32_t now) {
  statusLedMode = mode;
  statusLedModeStartMs = now;
  if (mode == StatusLedMode::kRuntimeSolid) {
    runtimeSolidPending = false;
  }
}

void requestSetupCompleteFlash(uint32_t now) {
  runtimeSolidPending = false;
  setStatusLedMode(StatusLedMode::kSetupCompleteFlash, now);
}

void requestRuntimeSolid(uint32_t now) {
  if (statusLedMode == StatusLedMode::kSetupCompleteFlash) {
    runtimeSolidPending = true;
    return;
  }

  setStatusLedMode(StatusLedMode::kRuntimeSolid, now);
}

void requestErrorBlink(uint32_t now) {
  setStatusLedMode(StatusLedMode::kErrorBlink, now);
}

void updateStatusLed(uint32_t now) {
  switch (statusLedMode) {
    case StatusLedMode::kSetupBreathing:
      updateSetupStatusLed(now);
      break;

    case StatusLedMode::kSetupCompleteFlash: {
      const uint32_t elapsedMs = now - statusLedModeStartMs;
      if (elapsedMs < kStatusLedSetupCompleteBlankMs) {
        setStatusLed(false);
      } else if (elapsedMs < kStatusLedSetupCompleteBlankMs + kStatusLedSetupCompleteFlashMs) {
        const uint32_t flashElapsedMs = elapsedMs - kStatusLedSetupCompleteBlankMs;
        setStatusLed((flashElapsedMs / kStatusLedSetupCompleteToggleMs) % 2 == 0);
      } else if (runtimeSolidPending) {
        setStatusLedMode(StatusLedMode::kRuntimeSolid, now);
        setStatusLed(true);
      } else {
        setStatusLed(false);
      }
      break;
    }

    case StatusLedMode::kRuntimeSolid:
      setStatusLed(true);
      break;

    case StatusLedMode::kErrorBlink:
      setStatusLed(((now - statusLedModeStartMs) / kStatusLedErrorFlashMs) % 2 == 0);
      break;
  }
}

void waitWithStatusLed(uint32_t durationMs) {
  const uint32_t startMs = millis();
  while (millis() - startMs < durationMs) {
    updateStatusLed(millis());
    delay(5);
  }
}

void showErrorStatusLedFor(uint32_t durationMs) {
  requestErrorBlink(millis());
  waitWithStatusLed(durationMs);
  setStatusLedMode(StatusLedMode::kSetupBreathing, millis());
}

void blinkStatusLedForever() {
  requestErrorBlink(millis());
  while (true) {
    updateStatusLed(millis());
    delay(5);
  }
}

void printPressedState(bool pressed) {
  Serial.print(pressed ? "pressed" : "released");
}

void printControllerPinout() {
  Serial.println("Controller pin map:");
  Serial.print("  BNO055 SDA: D4 / GPIO ");
  Serial.println(kSdaGpioNumber);
  Serial.print("  BNO055 SCL: D5 / GPIO ");
  Serial.println(kSclGpioNumber);
  Serial.print("  button1: D1 / GPIO ");
  Serial.print(kButton1GpioNumber);
  Serial.println(" -> button -> GND, INPUT_PULLUP");
  Serial.print("  button2: D2 / GPIO ");
  Serial.print(kButton2GpioNumber);
  Serial.println(" -> button -> GND, INPUT_PULLUP");
  Serial.print("  status LED: D10 / GPIO ");
  Serial.print(kStatusLedGpioNumber);
  Serial.println(" -> resistor -> LED anode, LED cathode -> GND");
}

void printButtonSnapshot(const char* prefix, bool button1Pressed, bool button2Pressed) {
  Serial.print(prefix);
  Serial.print("button1=");
  printPressedState(button1Pressed);
  Serial.print(", button2=");
  printPressedState(button2Pressed);
  Serial.println();
}

void reportButtonChanges(bool button1Pressed, bool button2Pressed) {
  if (!kSerialDebugEnabled) {
    return;
  }

  if (hasLastReportedButtons && lastReportedButton1Pressed == button1Pressed &&
      lastReportedButton2Pressed == button2Pressed) {
    return;
  }

  printButtonSnapshot("Button state changed: ", button1Pressed, button2Pressed);
  hasLastReportedButtons = true;
  lastReportedButton1Pressed = button1Pressed;
  lastReportedButton2Pressed = button2Pressed;
}

void printI2cScan() {
  if (!kSerialDebugEnabled) {
    return;
  }

  Serial.println("Scanning I2C bus...");
  uint8_t deviceCount = 0;
  for (uint8_t address = 1; address < 127; ++address) {
    Wire.beginTransmission(address);
    const uint8_t error = Wire.endTransmission();
    if (error == 0) {
      Serial.print("  found device at 0x");
      if (address < 16) {
        Serial.print("0");
      }
      Serial.println(address, HEX);
      ++deviceCount;
    } else if (error == 4) {
      Serial.print("  unknown I2C error at 0x");
      if (address < 16) {
        Serial.print("0");
      }
      Serial.println(address, HEX);
    }
  }

  if (deviceCount == 0) {
    Serial.println("  no I2C devices found; check 3V3, GND, SDA, and SCL wiring");
  }
}

void printBnoDetails() {
  if (!kSerialDebugEnabled) {
    return;
  }

  sensor_t sensor;
  bno.getSensor(&sensor);
  Serial.println("BNO055 details:");
  Serial.print("  sensor: ");
  Serial.println(sensor.name);
  Serial.print("  driver version: ");
  Serial.println(sensor.version);
  Serial.print("  sensor id: ");
  Serial.println(sensor.sensor_id);
  Serial.print("  max value: ");
  Serial.println(sensor.max_value);
  Serial.print("  min value: ");
  Serial.println(sensor.min_value);
  Serial.print("  resolution: ");
  Serial.println(sensor.resolution);
}

void printRuntimeHealth(uint32_t now, const imu::Quaternion& quaternion,
                        bool button1Pressed, bool button2Pressed) {
  if (!kSerialDebugEnabled) {
    return;
  }

  if (lastHealthReportMs != 0 && now - lastHealthReportMs < kHealthReportIntervalMs) {
    return;
  }
  lastHealthReportMs = now;

  uint8_t systemCalibration = 0;
  uint8_t gyroCalibration = 0;
  uint8_t accelCalibration = 0;
  uint8_t magCalibration = 0;
  bno.getCalibration(&systemCalibration, &gyroCalibration, &accelCalibration, &magCalibration);

  Serial.println("Health:");
  Serial.print("  uptime_ms=");
  Serial.println(now);
  Serial.print("  wifi=");
  Serial.print(wifiStatusToString(WiFi.status()));
  Serial.print(" rssi=");
  Serial.print(WiFi.RSSI());
  Serial.print(" local_ip=");
  Serial.println(WiFi.localIP());
  Serial.print("  udp_sent=");
  Serial.println(udpSendCount);
  Serial.print("  host_ip=");
  if (hasHostIp) {
    Serial.println(hostIp);
  } else {
    Serial.println("not discovered");
  }
  Serial.print("  quaternion w=");
  Serial.print(quaternion.w(), 4);
  Serial.print(" x=");
  Serial.print(quaternion.x(), 4);
  Serial.print(" y=");
  Serial.print(quaternion.y(), 4);
  Serial.print(" z=");
  Serial.println(quaternion.z(), 4);
  Serial.print("  calibration sys=");
  Serial.print(systemCalibration);
  Serial.print(" gyro=");
  Serial.print(gyroCalibration);
  Serial.print(" accel=");
  Serial.print(accelCalibration);
  Serial.print(" mag=");
  Serial.println(magCalibration);
  printButtonSnapshot("  buttons ", button1Pressed, button2Pressed);
}

void printVisibleNetworks() {
  if (!kSerialDebugEnabled) {
    return;
  }

  Serial.println("Scanning for visible Wi-Fi networks...");
  WiFi.scanNetworks(true);
  const uint32_t scanStartMs = millis();
  int networkCount = WiFi.scanComplete();
  while (networkCount == -1 && millis() - scanStartMs < kWifiScanTimeoutMs) {
    updateStatusLed(millis());
    delay(5);
    networkCount = WiFi.scanComplete();
  }

  if (networkCount == -1) {
    Serial.println("Wi-Fi scan timed out.");
    WiFi.scanDelete();
    return;
  }

  if (networkCount <= 0) {
    Serial.println("No Wi-Fi networks found.");
    WiFi.scanDelete();
    return;
  }

  Serial.print("Found ");
  Serial.print(networkCount);
  Serial.println(" network(s):");
  for (int i = 0; i < networkCount; ++i) {
    Serial.print("  ");
    Serial.print(i + 1);
    Serial.print(". ");
    Serial.print(WiFi.SSID(i));
    Serial.print(" RSSI=");
    Serial.print(WiFi.RSSI(i));
    Serial.print(" dBm");
    Serial.print(" channel=");
    Serial.print(WiFi.channel(i));
    Serial.print(" ");
    Serial.println(WiFi.encryptionType(i) == WIFI_AUTH_OPEN ? "open" : "secured");
  }
  WiFi.scanDelete();
}

void printWifiStatusLine(const char* prefix, wl_status_t status) {
  Serial.print(prefix);
  Serial.print(wifiStatusToString(status));
  Serial.print(" (");
  Serial.print(static_cast<int>(status));
  Serial.println(")");
}

void resetWifiRadio() {
  Serial.println("Resetting Wi-Fi radio...");
  WiFi.disconnect(true, true);
  waitWithStatusLed(250);
  WiFi.mode(WIFI_OFF);
  waitWithStatusLed(250);
  WiFi.mode(WIFI_STA);
  waitWithStatusLed(250);
}

bool connectToWifi() {
  ++wifiAttemptCount;
  resetWifiRadio();

  Serial.println();
  Serial.print("Wi-Fi attempt #");
  Serial.println(wifiAttemptCount);
  Serial.println("Wi-Fi setup:");
  Serial.print("  Hostname: ");
  Serial.println(kWifiHostname);
  Serial.print("  SSID: ");
  Serial.println(kWifiSecretsSsid);
  Serial.print("  Host IP: ");
  Serial.println(kWifiSecretsHostIp);
  Serial.print("  Discovery port: ");
  Serial.println(kDiscoveryPort);
  Serial.print("  UDP port: ");
  Serial.println(kHostPort);

  printVisibleNetworks();

  Serial.print("Connecting to Wi-Fi");
  WiFi.setHostname(kWifiHostname);
  WiFi.begin(kWifiSecretsSsid, kWifiSecretsPassword);
  const uint32_t connectStartMs = millis();
  uint32_t lastProgressDotMs = 0;
  wl_status_t lastStatus = WiFi.status();
  printWifiStatusLine("Initial Wi-Fi status: ", lastStatus);

  while ((millis() - connectStartMs) < kWifiConnectTimeoutMs) {
    const uint32_t now = millis();
    const wl_status_t status = WiFi.status();
    if (status == WL_CONNECTED) {
      Serial.println();
      Serial.print("Wi-Fi connected. Local IP: ");
      Serial.println(WiFi.localIP());
      Serial.print("Signal strength: ");
      Serial.print(WiFi.RSSI());
      Serial.println(" dBm");
      return true;
    }

    if (status != lastStatus) {
      Serial.println();
      printWifiStatusLine("Wi-Fi status changed: ", status);
      lastStatus = status;
      Serial.print("Connecting to Wi-Fi");
    }

    if (now - lastProgressDotMs >= 500) {
      Serial.print(".");
      lastProgressDotMs = now;
    }
    updateStatusLed(now);
    delay(5);
  }

  Serial.println();
  Serial.println("Wi-Fi connection timed out.");
  printWifiStatusLine("Final Wi-Fi status: ", WiFi.status());
  printVisibleNetworks();
  Serial.println("If this keeps failing, test with a simple 2.4 GHz phone hotspot to separate router issues from board issues.");
  showErrorStatusLedFor(4000);
  return false;
}

bool discoverHost() {
  if (hasHostIp) {
    return true;
  }

  Serial.println("Listening for controller game server broadcast...");
  Serial.print("  Discovery port: ");
  Serial.println(kDiscoveryPort);
  Serial.print("  Expected message: ");
  Serial.println(kDiscoveryMessage);

  if (!discoveryUdp.begin(kDiscoveryPort)) {
    Serial.println("Failed to open UDP discovery listener.");
    showErrorStatusLedFor(3000);
    return false;
  }

  uint32_t lastDiscoveryHeartbeatMs = 0;
  while (!hasHostIp) {
    const uint32_t now = millis();
    updateStatusLed(now);

    if (lastDiscoveryHeartbeatMs == 0 ||
        now - lastDiscoveryHeartbeatMs >= kDiscoveryHeartbeatIntervalMs) {
      Serial.print("Still listening for server discovery on UDP ");
      Serial.print(kDiscoveryPort);
      Serial.print(" from local IP ");
      Serial.println(WiFi.localIP());
      lastDiscoveryHeartbeatMs = now;
    }

    if (WiFi.status() != WL_CONNECTED) {
      Serial.println("Wi-Fi disconnected while waiting for server discovery.");
      discoveryUdp.stop();
      return false;
    }

    const int packetSize = discoveryUdp.parsePacket();
    if (packetSize <= 0) {
      delay(5);
      continue;
    }

    char packet[96];
    const int bytesRead =
        discoveryUdp.read(packet, static_cast<int>(sizeof(packet) - 1));
    if (bytesRead <= 0) {
      delay(5);
      continue;
    }
    packet[bytesRead] = '\0';

    Serial.print("Discovery packet from ");
    Serial.print(discoveryUdp.remoteIP());
    Serial.print(":");
    Serial.print(discoveryUdp.remotePort());
    Serial.print(" -> ");
    Serial.println(packet);

    if (strcmp(packet, kDiscoveryMessage) != 0) {
      Serial.println("Ignoring unexpected discovery payload.");
      delay(5);
      continue;
    }

    hostIp = discoveryUdp.remoteIP();
    hasHostIp = true;
  }

  discoveryUdp.stop();
  Serial.print("Locked server IP: ");
  Serial.println(hostIp);
  requestSetupCompleteFlash(millis());
  Serial.println("Status LED: setup complete flash.");
  return true;
}
}  // namespace

void setup() {
  pinMode(kButton1Pin, INPUT_PULLUP);
  pinMode(kButton2Pin, INPUT_PULLUP);
  pinMode(kStatusLedPin, OUTPUT);
  setStatusLed(false);

  Serial.begin(kBaudRate);
  const uint32_t bootStartMs = millis();
  while (!Serial && (millis() - bootStartMs) < 1500) {
    updateStatusLed(millis());
    delay(5);
  }

  Serial.println();
  Serial.println("XIAO ESP32-C3 + BNO055 UDP sender");
  printControllerPinout();
  printButtonSnapshot("Initial buttons: ", readButtonPressed(kButton1Pin), readButtonPressed(kButton2Pin));
  Serial.print("Quiet startup window: ");
  Serial.print(kStartupQuietMs);
  Serial.println(" ms");
  waitWithStatusLed(kStartupQuietMs);

  Wire.begin(kSdaPin, kSclPin);
  Wire.setClock(kI2cClockHz);
  Serial.print("I2C started at ");
  Serial.print(kI2cClockHz);
  Serial.println(" Hz.");
  printI2cScan();

  Serial.println("Initializing BNO055...");
  updateStatusLed(millis());
  if (!bno.begin()) {
    Serial.println("BNO055 not detected.");
    blinkStatusLedForever();
  }

  waitWithStatusLed(1000);
  bno.setExtCrystalUse(true);
  Serial.println("BNO055 detected.");
  printBnoDetails();

  while (!connectToWifi()) {
    Serial.print("Retrying Wi-Fi connection in ");
    Serial.print(kWifiRetryDelayMs);
    Serial.println(" ms...");
    waitWithStatusLed(kWifiRetryDelayMs);
  }

  while (!discoverHost()) {
    if (WiFi.status() == WL_CONNECTED) {
      Serial.println("Still waiting for a valid server discovery packet...");
      waitWithStatusLed(250);
      continue;
    }

    while (!connectToWifi()) {
      Serial.print("Retrying Wi-Fi connection in ");
      Serial.print(kWifiRetryDelayMs);
      Serial.println(" ms...");
      waitWithStatusLed(kWifiRetryDelayMs);
    }
  }
}

void loop() {
  const uint32_t now = millis();
  updateStatusLed(now);

  if (now - lastPacketMs < kPacketIntervalMs) {
    return;
  }
  lastPacketMs = now;

  const imu::Quaternion quaternion = bno.getQuat();
  const float quatW = quaternion.w();
  const float quatX = quaternion.x();
  const float quatY = quaternion.y();
  const float quatZ = quaternion.z();
  const bool button1Pressed = readButtonPressed(kButton1Pin);
  const bool button2Pressed = readButtonPressed(kButton2Pin);
  reportButtonChanges(button1Pressed, button2Pressed);
  printRuntimeHealth(now, quaternion, button1Pressed, button2Pressed);

  const bool shouldSend =
      !hasLastSentFrame || quaternionComponentChangedEnough(lastSentQuatW, quatW) ||
      quaternionComponentChangedEnough(lastSentQuatX, quatX) ||
      quaternionComponentChangedEnough(lastSentQuatY, quatY) ||
      quaternionComponentChangedEnough(lastSentQuatZ, quatZ) ||
      lastSentButton1Pressed != button1Pressed || lastSentButton2Pressed != button2Pressed ||
      lastSuccessfulSendMs == 0 || now - lastSuccessfulSendMs >= kHeartbeatIntervalMs;
  if (!shouldSend) {
    return;
  }

  char packet[128];
  snprintf(packet, sizeof(packet), "qw=%.5f,qx=%.5f,qy=%.5f,qz=%.5f,button1=%d,button2=%d",
           quatW, quatX, quatY, quatZ, button1Pressed ? 1 : 0, button2Pressed ? 1 : 0);

  if (WiFi.status() != WL_CONNECTED) {
    Serial.println("Wi-Fi disconnected while sending. Attempting reconnect...");
    while (!connectToWifi()) {
      Serial.print("Retrying Wi-Fi connection in ");
      Serial.print(kWifiRetryDelayMs);
      Serial.println(" ms...");
      waitWithStatusLed(kWifiRetryDelayMs);
    }
  }

  if (!hasHostIp) {
    Serial.println("No discovered host IP is available.");
    showErrorStatusLedFor(3000);
    return;
  }

  if (!udp.beginPacket(hostIp, kHostPort)) {
    Serial.println("Failed to begin UDP packet.");
    showErrorStatusLedFor(3000);
    return;
  }

  udp.write(reinterpret_cast<const uint8_t*>(packet), strlen(packet));
  if (!udp.endPacket()) {
    Serial.println("Failed to send UDP packet.");
    showErrorStatusLedFor(3000);
    return;
  }

  ++udpSendCount;
  lastSuccessfulSendMs = now;
  hasLastSentFrame = true;
  lastSentQuatW = quatW;
  lastSentQuatX = quatX;
  lastSentQuatY = quatY;
  lastSentQuatZ = quatZ;
  lastSentButton1Pressed = button1Pressed;
  lastSentButton2Pressed = button2Pressed;
  requestRuntimeSolid(millis());
  Serial.print("UDP #");
  Serial.print(udpSendCount);
  Serial.print(" sent to ");
  Serial.print(hostIp);
  Serial.print(":");
  Serial.print(kHostPort);
  Serial.print(" -> ");
  Serial.println(packet);
}

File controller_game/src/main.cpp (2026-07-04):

#include <sstream>
#include <string>
#include <vector>

#if defined(_WIN32)
#include "platform/platform_windows.h"
#else
#include "platform/platform_linux.h"
#endif

#include "app/app_mode.h"
#include "app/app_renderer.h"
#include "app/app_runtime.h"
#include "app/frame_input.h"
#include "app/hotkeys.h"
#include "app/menu_flow.h"
#include "app/performance_log.h"
#include "app/server_discovery.h"
#include "game/game_audio.h"
#include "game/game_logic.h"
#include "raylib.h"

namespace {
constexpr int kUdpPort = 4210;
constexpr const char* kNoActiveIpv4AddressMessage = "No active IPv4 address found";
std::string JoinLocalIps(const std::vector<std::string>& addresses) {
  std::ostringstream joined;
  for (size_t i = 0; i < addresses.size(); ++i) {
    if (i > 0) {
      joined << ", ";
    }
    joined << addresses[i];
  }
  return joined.str();
}

bool HasActiveIpv4Address(const std::vector<std::string>& addresses) {
  return !addresses.empty() && addresses.front() != kNoActiveIpv4AddressMessage;
}

}  // namespace

int main() {
  platform::UdpReceiver receiver;
  platform::UdpBroadcaster broadcaster;
  const bool udpReady = receiver.Open(kUdpPort);
  const bool broadcastReady = broadcaster.Open();
  const std::vector<std::string> localIpAddresses = platform::GetLocalIpv4Addresses();
  const std::string localIpText = JoinLocalIps(localIpAddresses);

  if (platform::kConsoleBuild) {
    bool networkReady = true;
    if (!HasActiveIpv4Address(localIpAddresses)) {
      std::printf("[startup] network unavailable: %s\n", localIpText.c_str());
      networkReady = false;
    }
    if (!udpReady) {
      std::printf("[startup] failed to open UDP listener on port %d\n", kUdpPort);
      networkReady = false;
    }
    if (!broadcastReady) {
      std::printf("[startup] failed to open UDP broadcast socket\n");
      networkReady = false;
    }
    if (!networkReady) {
      std::printf("[startup] exiting so the Pi console stays available for network recovery.\n");
      return 1;
    }
  }

  SetConfigFlags(platform::GetWindowConfigFlags());
  InitWindow(platform::kWindowWidth, platform::kWindowHeight, platform::kWindowTitle);
  platform::ApplyPostWindowInit();
  SetTargetFPS(60);
  InitAudioDevice();

  AppRuntime app = LoadAppRuntime();

  while (!app.shouldQuit && !WindowShouldClose()) {
    const auto frameStartTime = PerfClock::now();
    auto inputStartTime = frameStartTime;
    if (platform::ShouldToggleFullscreen()) {
      ToggleFullscreen();
    }
    if (!app.pauseMenu.active && IsKeyPressed(KEY_T)) {
      app.appMode = app.appMode == AppMode::kGame ? AppMode::kHardwareTest : AppMode::kGame;
    }
    HandleGameHotkeys(app.pauseMenu.active, app.appMode, &app.game, &app.roadArtEditor,
                      &app.roadArtTuning, app.roadArtTuningPath, &app.cameraZoomScale);
    HandleHardwareTestHotkeys(app.pauseMenu.active, app.appMode, &app.displayAxis);

    const FrameInput input = ReadFrameInput(&app, &receiver);
    const auto inputEndTime = PerfClock::now();

    UpdateServerDiscoveryBeacon(&app.discovery, &broadcaster, broadcastReady,
                                input.hasFreshPackets, app.lastPacketTime, input.now);
    UpdateMenusAndOverlays(&app, input);

    const auto updateStartTime = PerfClock::now();
    if (app.appMode == AppMode::kGame && !app.pauseMenu.active) {
      UpdateGame(&app.game, input.gameSteeringInput, input.gameButtons, input.dt, &app.city);
    }
    const auto updateEndTime = PerfClock::now();
    const auto audioStartTime = updateEndTime;
    UpdateGameAudio(&app.gameAudio, app.game,
                    app.appMode == AppMode::kGame && !app.pauseMenu.active);
    const auto audioEndTime = PerfClock::now();

    const auto drawStartTime = PerfClock::now();
    DrawApp(app, input, udpReady, localIpText);
    const auto frameEndTime = PerfClock::now();
    AddPerformanceSample(
        &app.performance, ElapsedMilliseconds(frameStartTime, frameEndTime),
        static_cast<double>(input.dt) * 1000.0,
        ElapsedMilliseconds(inputStartTime, inputEndTime),
        ElapsedMilliseconds(updateStartTime, updateEndTime),
        ElapsedMilliseconds(audioStartTime, audioEndTime),
        ElapsedMilliseconds(drawStartTime, frameEndTime));
    MaybeLogPerformance(&app.performance, app.appMode, app.pauseMenu.active);
  }

  UnloadAppRuntime(&app);
  if (IsAudioDeviceReady()) {
    CloseAudioDevice();
  }
  CloseWindow();
  return 0;
}

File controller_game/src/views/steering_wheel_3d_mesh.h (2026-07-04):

#pragma once

#include <algorithm>
#include <cmath>
#include <vector>

#include "raylib.h"

namespace steering_wheel_3d_mesh {
constexpr float kPi = 3.14159265358979323846f;
constexpr float kTwoPi = kPi * 2.0f;

struct MeshBuilder {
  std::vector<Vector3> vertices;
  std::vector<Vector3> normals;
  std::vector<Vector2> texcoords;
  std::vector<unsigned short> indices;
};

inline unsigned short AddVertex(MeshBuilder* builder, Vector3 vertex, Vector3 normal,
                                Vector2 texcoord) {
  builder->vertices.push_back(vertex);
  builder->normals.push_back(normal);
  builder->texcoords.push_back(texcoord);
  return static_cast<unsigned short>(builder->vertices.size() - 1);
}

inline void AddQuad(MeshBuilder* builder, Vector3 a, Vector3 b, Vector3 c, Vector3 d,
                    Vector3 normal) {
  const unsigned short base = static_cast<unsigned short>(builder->vertices.size());
  AddVertex(builder, a, normal, Vector2{0.0f, 0.0f});
  AddVertex(builder, b, normal, Vector2{1.0f, 0.0f});
  AddVertex(builder, c, normal, Vector2{1.0f, 1.0f});
  AddVertex(builder, d, normal, Vector2{0.0f, 1.0f});
  builder->indices.push_back(base);
  builder->indices.push_back(static_cast<unsigned short>(base + 1));
  builder->indices.push_back(static_cast<unsigned short>(base + 2));
  builder->indices.push_back(base);
  builder->indices.push_back(static_cast<unsigned short>(base + 2));
  builder->indices.push_back(static_cast<unsigned short>(base + 3));
}

inline Mesh UploadBuiltMesh(const MeshBuilder& builder) {
  Mesh mesh = {};
  mesh.vertexCount = static_cast<int>(builder.vertices.size());
  mesh.triangleCount = static_cast<int>(builder.indices.size() / 3);
  mesh.vertices = static_cast<float*>(MemAlloc(sizeof(float) * 3 * builder.vertices.size()));
  mesh.normals = static_cast<float*>(MemAlloc(sizeof(float) * 3 * builder.normals.size()));
  mesh.texcoords = static_cast<float*>(MemAlloc(sizeof(float) * 2 * builder.texcoords.size()));
  mesh.indices =
      static_cast<unsigned short*>(MemAlloc(sizeof(unsigned short) * builder.indices.size()));

  for (size_t i = 0; i < builder.vertices.size(); ++i) {
    mesh.vertices[i * 3 + 0] = builder.vertices[i].x;
    mesh.vertices[i * 3 + 1] = builder.vertices[i].y;
    mesh.vertices[i * 3 + 2] = builder.vertices[i].z;
    mesh.normals[i * 3 + 0] = builder.normals[i].x;
    mesh.normals[i * 3 + 1] = builder.normals[i].y;
    mesh.normals[i * 3 + 2] = builder.normals[i].z;
    mesh.texcoords[i * 2 + 0] = builder.texcoords[i].x;
    mesh.texcoords[i * 2 + 1] = builder.texcoords[i].y;
  }

  std::copy(builder.indices.begin(), builder.indices.end(), mesh.indices);
  UploadMesh(&mesh, false);
  return mesh;
}

inline Mesh GenerateTorusMesh(float majorRadius, float tubeRadius, int ringSegments,
                              int tubeSegments) {
  MeshBuilder builder;
  for (int ring = 0; ring < ringSegments; ++ring) {
    const float u = static_cast<float>(ring) / static_cast<float>(ringSegments) * kTwoPi;
    const float cosU = std::cos(u);
    const float sinU = std::sin(u);
    for (int tube = 0; tube < tubeSegments; ++tube) {
      const float v = static_cast<float>(tube) / static_cast<float>(tubeSegments) * kTwoPi;
      const float cosV = std::cos(v);
      const float sinV = std::sin(v);
      const Vector3 normal = Vector3{cosU * cosV, sinU * cosV, sinV};
      const Vector3 vertex = Vector3{(majorRadius + tubeRadius * cosV) * cosU,
                                     (majorRadius + tubeRadius * cosV) * sinU,
                                     tubeRadius * sinV};
      AddVertex(&builder, vertex, normal,
                Vector2{static_cast<float>(ring) / ringSegments,
                        static_cast<float>(tube) / tubeSegments});
    }
  }

  for (int ring = 0; ring < ringSegments; ++ring) {
    const int nextRing = (ring + 1) % ringSegments;
    for (int tube = 0; tube < tubeSegments; ++tube) {
      const int nextTube = (tube + 1) % tubeSegments;
      const unsigned short a = static_cast<unsigned short>(ring * tubeSegments + tube);
      const unsigned short b = static_cast<unsigned short>(nextRing * tubeSegments + tube);
      const unsigned short c = static_cast<unsigned short>(nextRing * tubeSegments + nextTube);
      const unsigned short d = static_cast<unsigned short>(ring * tubeSegments + nextTube);
      builder.indices.push_back(a);
      builder.indices.push_back(b);
      builder.indices.push_back(c);
      builder.indices.push_back(a);
      builder.indices.push_back(c);
      builder.indices.push_back(d);
    }
  }

  return UploadBuiltMesh(builder);
}
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

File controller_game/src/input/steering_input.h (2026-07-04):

#pragma once

#include <algorithm>
#include <cmath>

#include "../game/game_logic.h"

constexpr float kSteeringKeyboardFallbackFullLockDeg = 45.0f;
constexpr float kSteeringInputDeadzoneDeg = 2.0f;
constexpr float kSteeringInputDeadzoneBlendDeg = 8.0f;
constexpr float kSteeringInputEarlyResponseFraction = 0.85f;
constexpr float kSteeringInputEarlyRangeDeg = 90.0f;
constexpr float kSteeringInputFullLockDeg = 270.0f;
constexpr float kSteeringKeyboardResponsePerSecond = 220.0f;
constexpr float kSteeringKeyboardReturnPerSecond = 280.0f;

struct SteeringInputState {
  SensorFrame centerFrame;
  bool hasCenterFrame = false;
  float manualAngleDeg = 0.0f;
  float accumulatedGameAngleDeg = 0.0f;
  float lastWrappedGameAngleDeg = 0.0f;
  bool hasLastWrappedGameAngle = false;
};

inline float GetWrappedGameWheelAngleDeg(const SensorFrame& frame,
                                         const SteeringInputState& steering) {
  return steering.hasCenterFrame
             ? GetCenteredAxisDegrees(OrientationAxis::kPitch, frame, steering.centerFrame)
             : GetAxisDegrees(OrientationAxis::kPitch, frame);
}

inline void ResetControllerCenter(const SensorFrame& lastGoodFrame, bool hasAnyPacket,
                                  SteeringInputState* steering) {
  if (hasAnyPacket) {
    steering->centerFrame = lastGoodFrame;
    steering->hasCenterFrame = true;
  } else {
    steering->manualAngleDeg = 0.0f;
    steering->hasCenterFrame = false;
  }
  steering->accumulatedGameAngleDeg = 0.0f;
  steering->lastWrappedGameAngleDeg = 0.0f;
  steering->hasLastWrappedGameAngle = false;
}
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

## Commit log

2026-05-31 Add toddler steering wheel CAD model
    [toddler_steering_wheel.step, toddler_steering_wheel.stl]
2026-06-01 Add modular hub CAD and Windows CadQuery setup
    [toddler_steering_wheel.step, toddler_steering_wheel.stl, toddler_steering_wheel_cartridge.step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]
2026-06-01 Refine keyed cartridge and add lid
    [toddler_steering_wheel.step, toddler_steering_wheel.stl, toddler_steering_wheel_cartridge.step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]
2026-06-05 Continued work on cartridge
    [toddler_steering_wheel.step, toddler_steering_wheel.stl, toddler_steering_wheel_cartridge.step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]
2026-06-05 Additional improvements
    [toddler_steering_wheel.step, toddler_steering_wheel_cartridge.step, toddler_steering_wheel_cartridge.stl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]
2026-06-06 Tweaks to slot
    [toddler_steering_wheel.step, toddler_steering_wheel_cartridge.step, toddler_steering_wheel_cartridge.stl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]
2026-06-06 Different layout to make room for buttons
    [toddler_steering_wheel.step, toddler_steering_wheel_cartridge.step, toddler_steering_wheel_cartridge.stl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]
2026-06-06 Buttons and other compartments)
    [toddler_steering_wheel.step, toddler_steering_wheel_cartridge.step, toddler_steering_wheel_cartridge.stl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]
2026-06-06 sensor pegs
    [toddler_steering_wheel.step, toddler_steering_wheel.stl, toddler_steering_wheel_cartridge.step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]
2026-06-08 major changes
    [steering_wheel_back.stl, steering_wheel_front.stl, test_screw_block.stl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]
2026-06-08 Further adjustments
    [steering_wheel_back.stl, toddler_steering_wheel.step, toddler_steering_wheel_cartridge_lid.step]
2026-06-08 Clean up
    [toddler_steering_wheel.step, toddler_steering_wheel.stl, toddler_steering_wheel_cartridge.step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]
2026-06-09 Additional adjustments
    [center_hub.stl, steering_wheel_back.stl, steering_wheel_front.stl]
2026-06-09 More changes
    [center_hub.stl, steering_wheel_back.stl]
2026-06-22 More progress
    [center_hub.stl, steering_wheel_back.stl, steering_wheel_front.stl]
2026-06-22 Additional tweaks
    [center_hub.stl, led_socket.stl, steering_wheel_front.stl]
2026-07-03 Add Raspberry Pi console deploy workflow
2026-07-03 Document Raspberry Pi deploy workflow
2026-07-03 Add controller discovery and quaternion steering
2026-07-03 Tune steering and button drive behavior
2026-07-03 Refine steering feel and controller reconnect behavior
2026-07-03 Add CSV city map visuals and Pi workflow split
    [demo_city.csv]
2026-07-04 Add city gameplay tuning and wheel visuals
    [demo_city.csv, road_art_tuning.csv]
2026-07-04 Polish steering, dust, and collision feel
    [city_map.h, game_logic.h, game_view.h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]
2026-07-04 Add controller pause menu and denser city
    [demo_city.csv]
2026-07-04 Add kraken encounters and sounds
    [demo_city.csv]
2026-07-04 Extract steering input helpers
2026-07-04 Make pause menu wheel scrolling continuous
2026-07-04 Render hardware test steering wheel in 3D
2026-07-04 Extract frame input snapshot
2026-07-04 Extract menu flow handling
2026-07-05 Checkpoint toddler steering wheel profile before tunnel update
2026-07-05 Refine steering wheel wire tunnel profile
    [center_hub.stl, steering_wheel_back.stl, steering_wheel_front.stl]
2026-07-05 Update steering wheel and controller game assets
    [center_hub.stl, demo_city.csv, steering_wheel_front.stl]
2026-07-05 Increase steering wheel LED hole size
    [steering_wheel_front.stl]
2026-07-06 Refine city layout and editor display
    [demo_city.csv]
